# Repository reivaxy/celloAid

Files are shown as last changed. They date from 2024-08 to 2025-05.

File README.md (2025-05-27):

# celloAid

Check the license file.

No commercial use is authorized.

This is a set of aids to play the cello.

## Hand aid

shell_x folders contain shells built from a scan of the hand needing some aid

shell_3 has a bendable finger to press on the bow



## Bow aid

bow_x folders contain several iteration of a device to help hold the bow.

bow_3 and bow_4 have adjustable finger positions and a choice of various finger sizes.

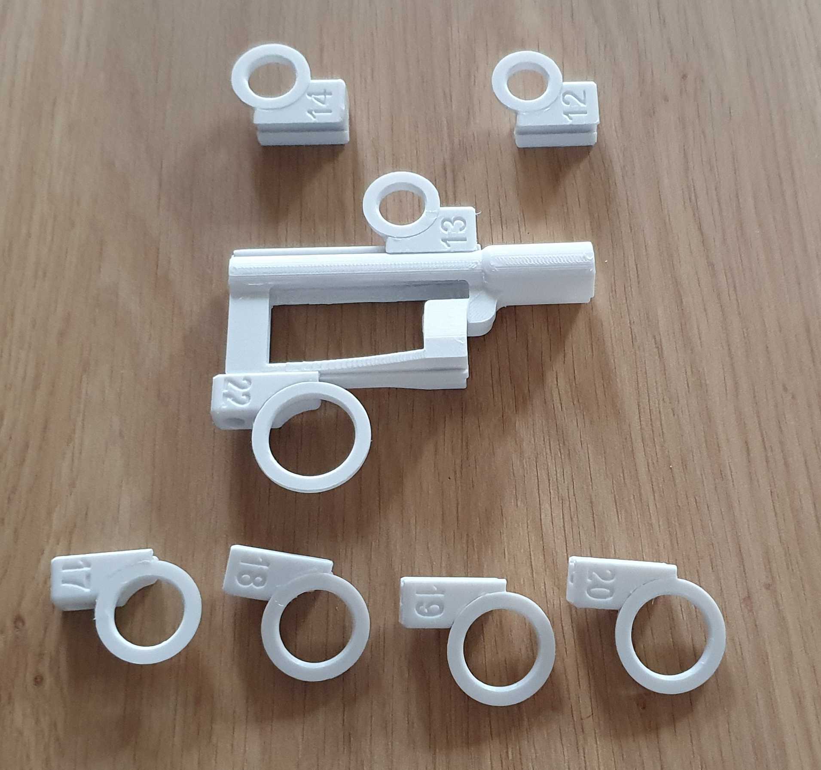
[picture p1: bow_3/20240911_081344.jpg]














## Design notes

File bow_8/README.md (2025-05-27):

This new prototype is an attempt at using the scan of the hand to offer accurate slots for the fingers.

The challenge of this approach is that nothing can be adjusted, we need to find the exact good position of the fingers relatively to each other and to the bow.

https://github.com/user-attachments/assets/44e5666f-47d5-4502-a32c-f4e456e8be6e



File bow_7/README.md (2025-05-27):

Unfortunately the silicon is too heavy, adding about 60g hence doubling the total weight of the device.

This new prototype is intended to be completed by thermo-plastic tightely adjusted around finger and thumb.

Therefore the finger and thumb slots were removed.

One challenge was to replace the low screw since it was on the removed thumb slot.

https://github.com/user-attachments/assets/684633d8-5a87-4853-8fdd-56d3ae45e7c3



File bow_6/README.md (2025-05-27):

bow_6 didn't provide enough grip, so I tried making the finger slots deeper. The top finger can now better push forward.

https://github.com/user-attachments/assets/e4d858df-fd63-4603-b8f2-d9ab5e832fca



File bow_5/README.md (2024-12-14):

New prototype without any hand shell, but only a device to put on the bow.

https://github.com/user-attachments/assets/7ac4e2ea-cd8e-4a7f-a282-7447c46ad186



Fingers will be set in silicon bi component mouldering putty to provide a firm grip.





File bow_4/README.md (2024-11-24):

The "nose" is longer and features a slidable pivot on which the hand aid bendable finger will be loosely attached to allow pressing down on the bow





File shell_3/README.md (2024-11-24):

Adding a bendable finger to press down on the bow



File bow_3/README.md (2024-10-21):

This iteration is intended to allow easy measurement for finger sizes and finger spacing.

Horizontal spacing is adjustable with rings sliding horizontally, with blocking screws, and sizing is made easy by changing the rings.

Small inconvenient is the sliders make the rings a bit farther from each other vertically, and some weight is added
(big slider + screw and nut), but it's just a prototype and once spacing and sizes are measured, next one will no longer be adjustable.

The hair tension can be adjusted at will without removing the device.



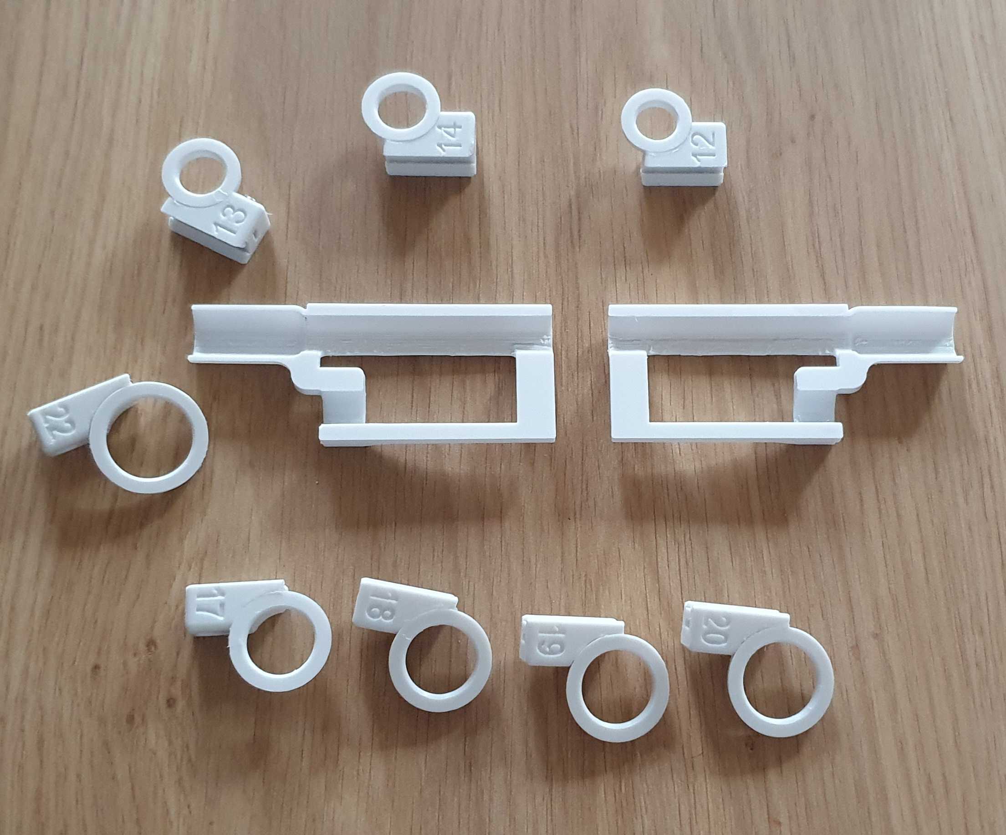
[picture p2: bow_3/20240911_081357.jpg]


To mitigate vertical spacing, I've worked on a new design for the thumb and finger rings, reducing distance by about 5mm.





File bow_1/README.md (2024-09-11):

One issue with this prototype is that it needs to be removed to adjust the hair tension.

The space between the two finger rings is too large for Soni

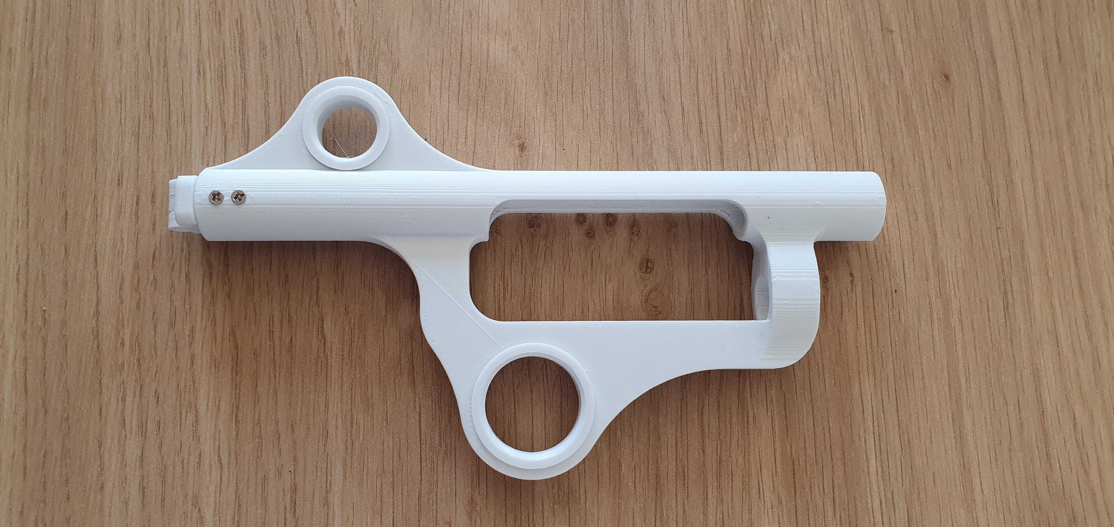
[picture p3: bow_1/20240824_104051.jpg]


A nice design is that the two halves are held together by the inner rings that also act as screws

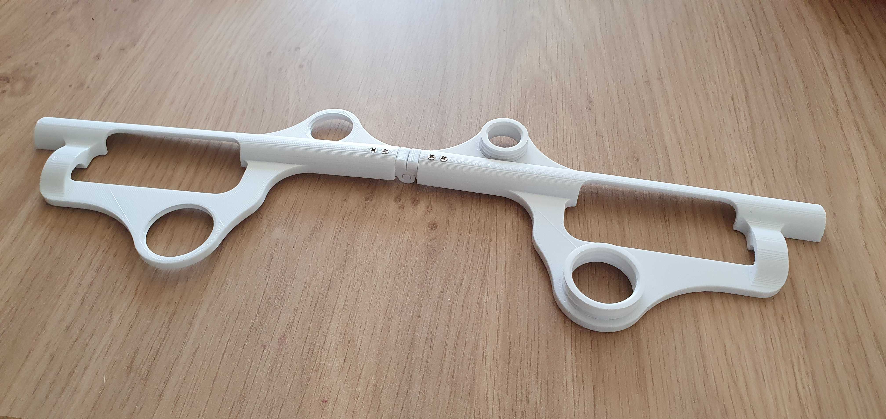
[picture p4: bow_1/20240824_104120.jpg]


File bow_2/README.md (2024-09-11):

Same issue than with bow_1 prototype, still needs to be removed to adjust the hair tension.

Compared to bow_1 prototype, the space between the two finger rings is better but not vertical enough to allow Soni use the full wrist flexion.

Also the finger rings are too large and don't provide a firm enough grip.

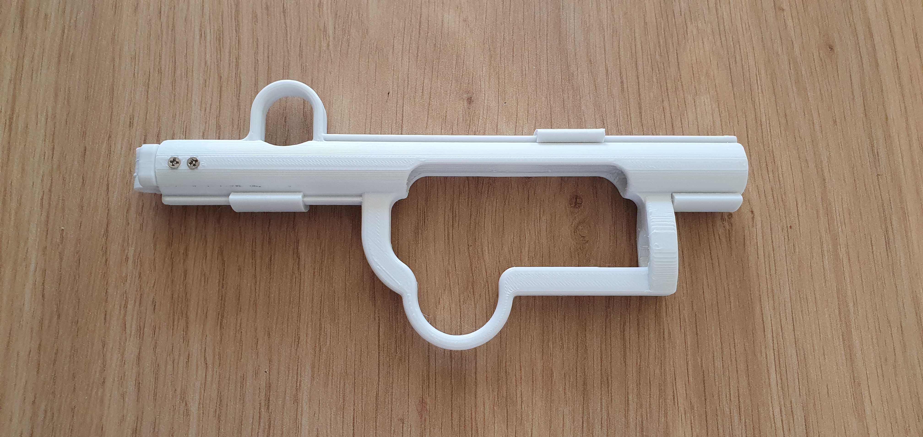
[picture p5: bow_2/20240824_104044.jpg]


The two halves are held together by sliding clips

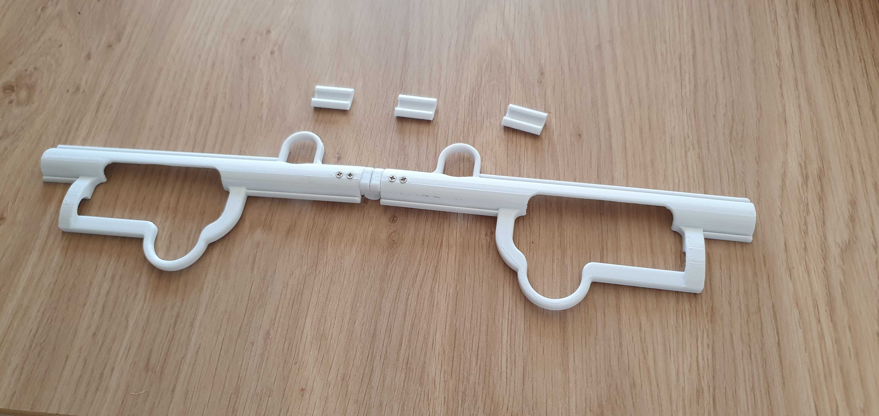
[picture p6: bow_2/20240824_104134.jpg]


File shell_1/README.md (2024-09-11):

This first shell was built from the scan from Soni's hand.

It was merely to validate designing a shell from a scan file.

It goes too low on the wrist which can no longer move enough, and too far on the fingers.

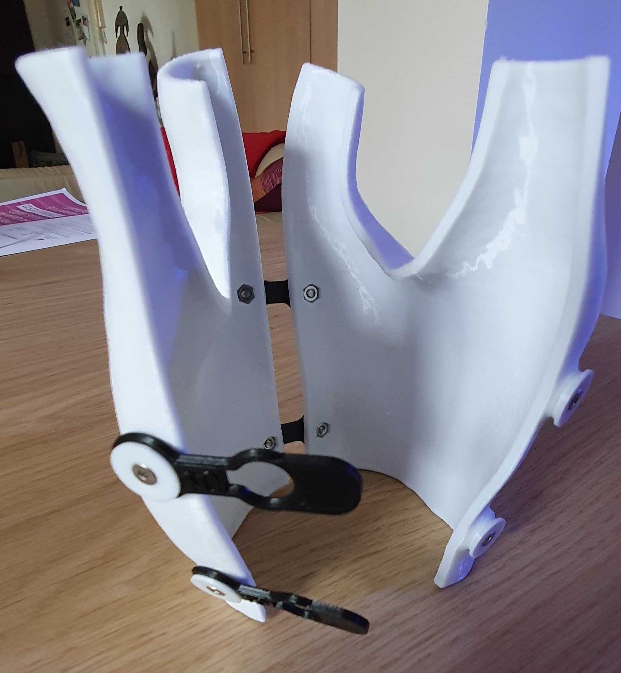
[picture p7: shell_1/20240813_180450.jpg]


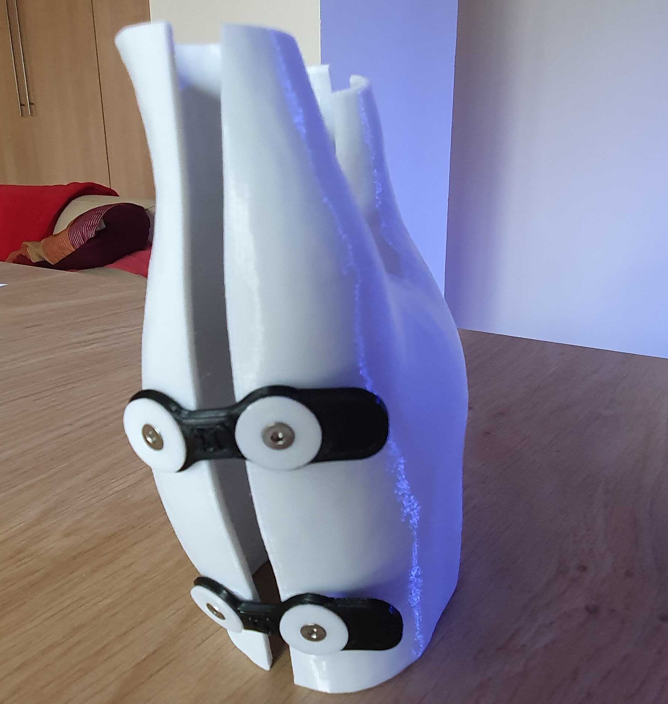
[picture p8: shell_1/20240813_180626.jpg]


Next iteration should have a third finger intended to apply some pressure on the bow.

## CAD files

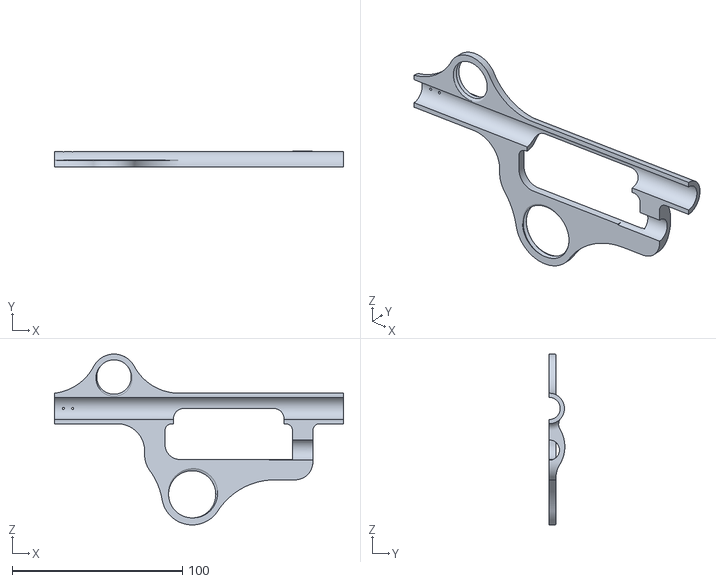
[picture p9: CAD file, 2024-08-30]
bow_1/tubeLeft.stl
170.0 x 9.24 x 100.5

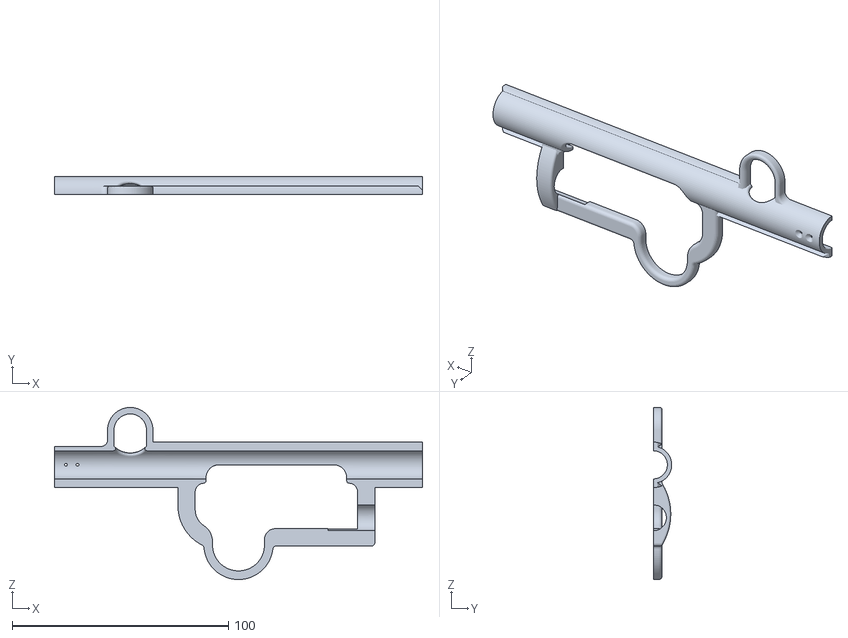
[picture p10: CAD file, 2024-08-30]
bow_2/tubeLeft.stl
170.0 x 8.50 x 79.5

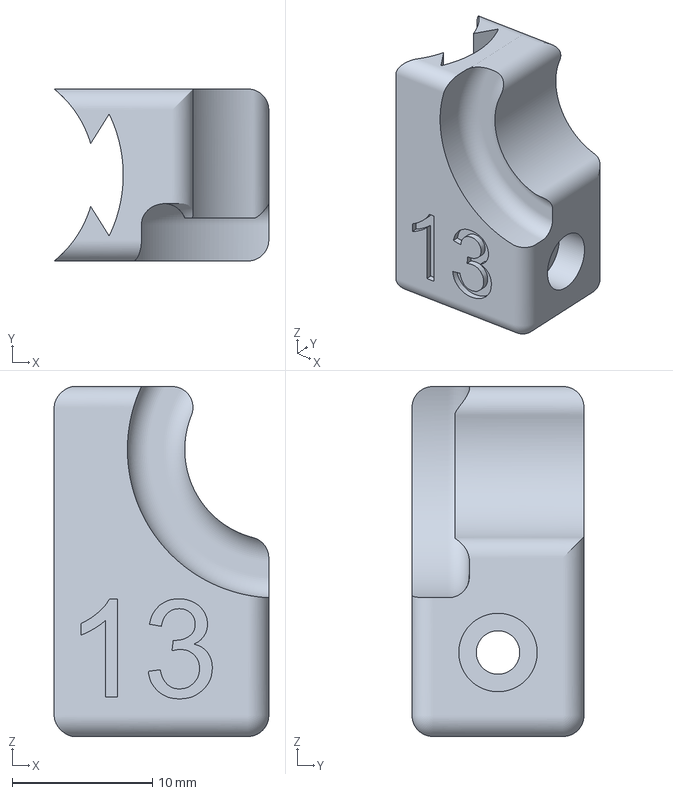
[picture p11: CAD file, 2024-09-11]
bow_3/finger/circles/fingerSlider13.3mf
15.3 x 12.3 x 25.0 mm

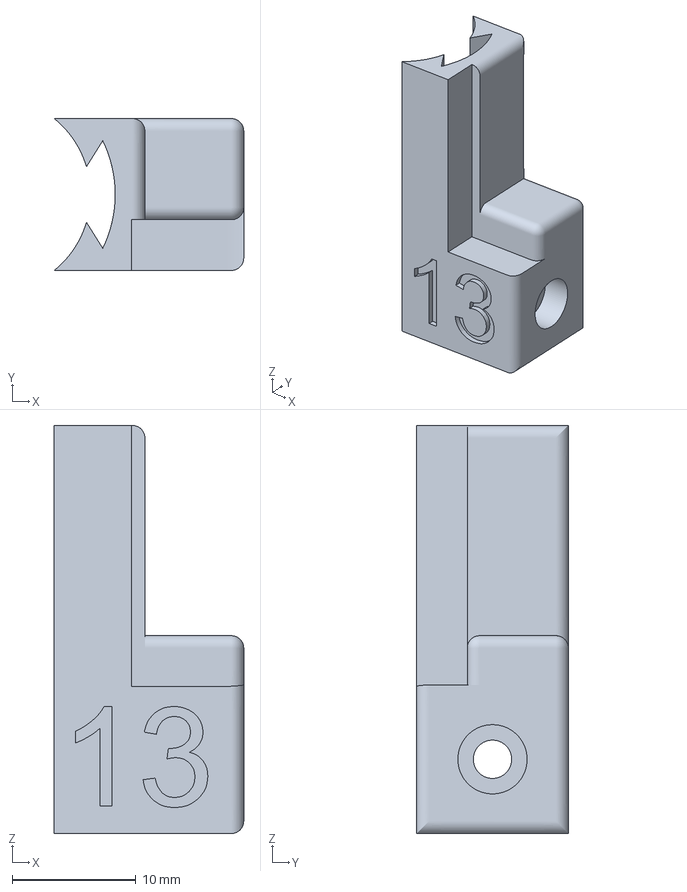
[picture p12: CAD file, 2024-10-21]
bow_3/finger/fingerSlider13.3mf
15.3 x 12.3 x 33.0 mm

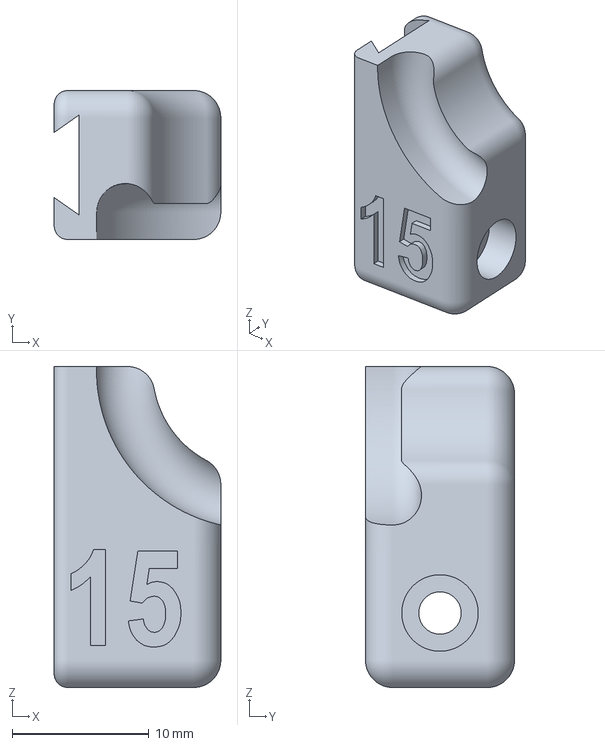
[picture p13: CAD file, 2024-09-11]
bow_3/thumb/circles/thumbSlider15.3mf
12.2 x 10.9 x 23.5 mm

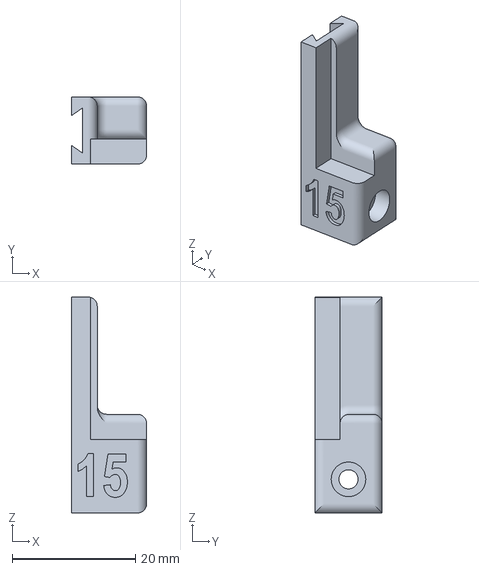
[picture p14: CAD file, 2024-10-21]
bow_3/thumb/thumbSlider15.3mf
12.2 x 10.9 x 35.0 mm

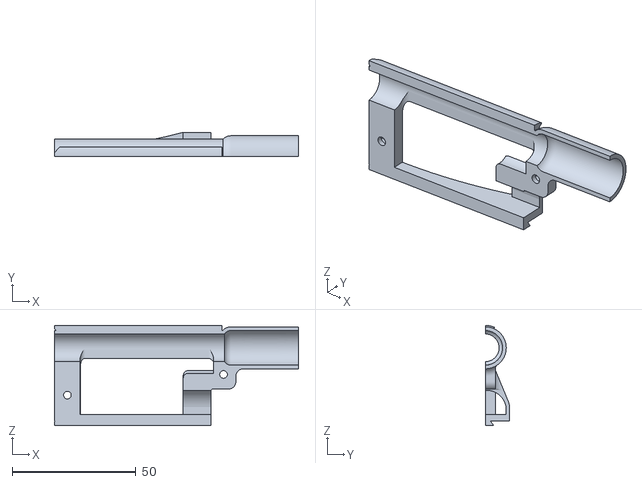
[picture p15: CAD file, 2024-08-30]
bow_3/tubeLeft.stl
98.7 x 9.90 x 40.6

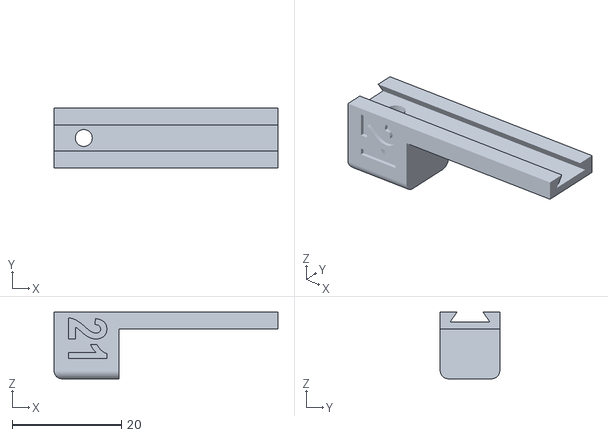
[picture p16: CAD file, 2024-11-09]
bow_4/thumbSlider21.stl
41.0 x 10.9 x 12.2

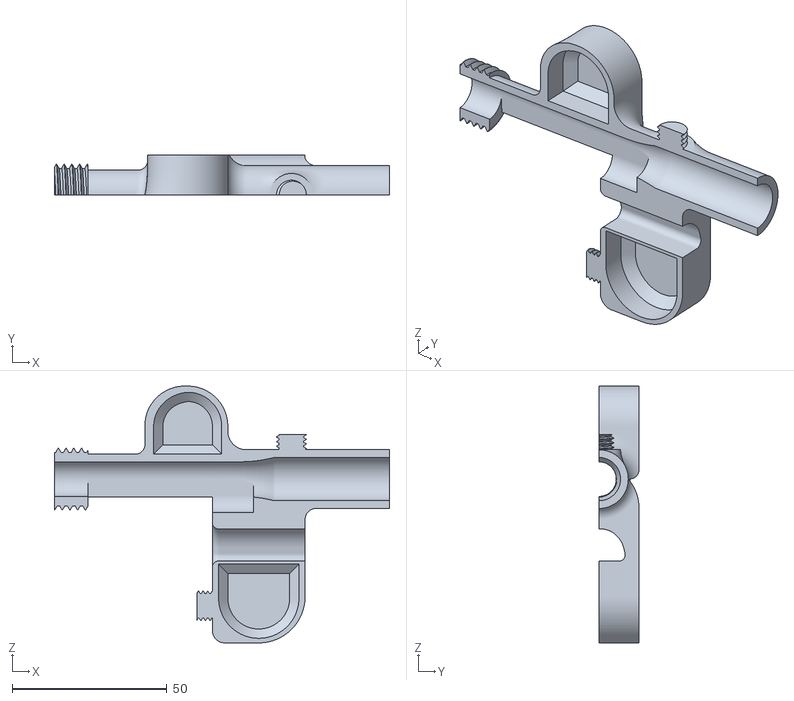
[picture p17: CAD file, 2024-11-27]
bow_5/bowBackHollow.stl
108.4 x 13.0 x 83.1

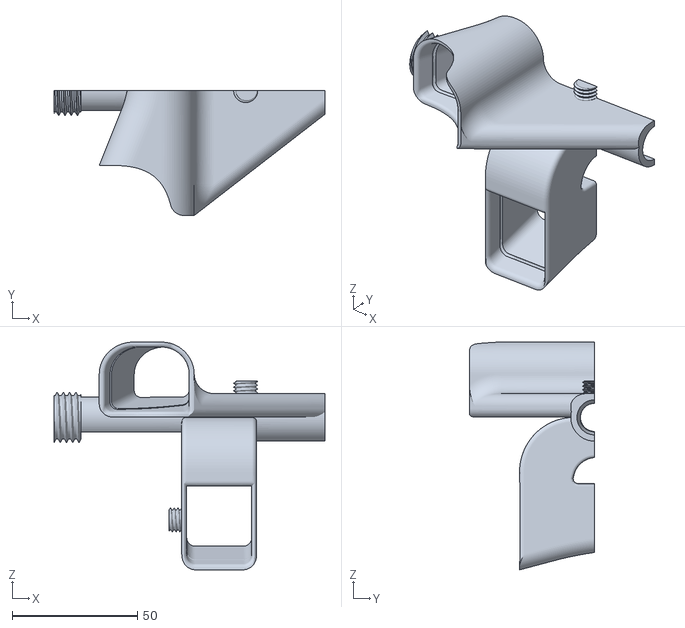
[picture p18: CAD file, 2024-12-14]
bow_6/front.stl
108.4 x 50.0 x 91.1

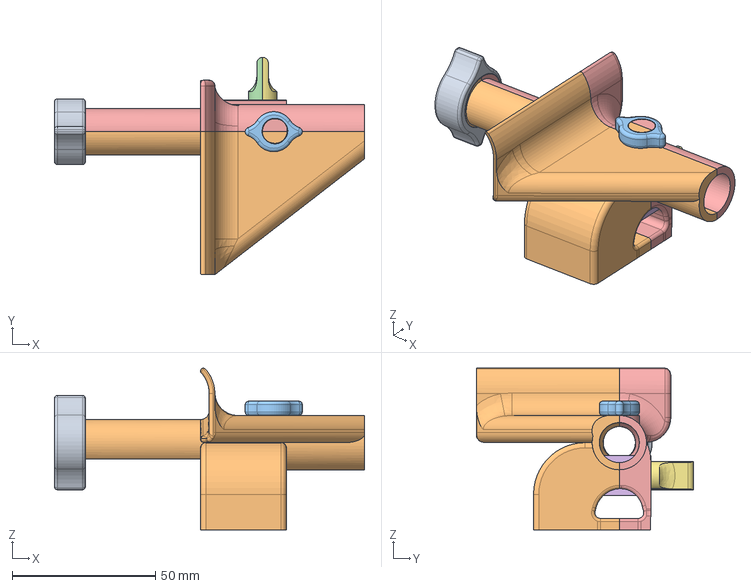
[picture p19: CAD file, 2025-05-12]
bow_7/step/bow_7.step
108.4 x 76.0 x 56.5 mm

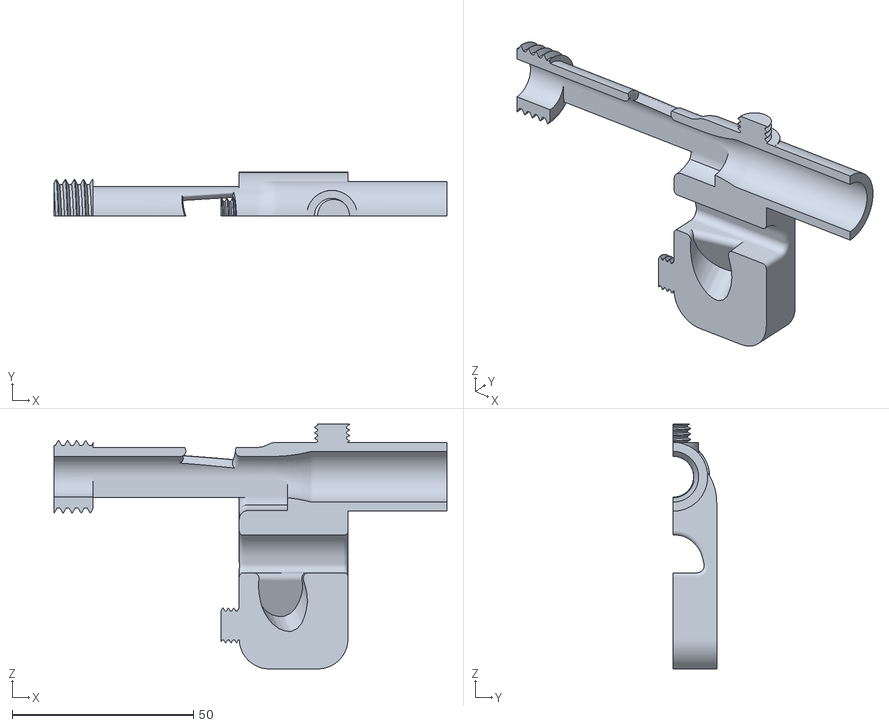
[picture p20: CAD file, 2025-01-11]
bow_8/back.stl
108.4 x 12.0 x 67.5

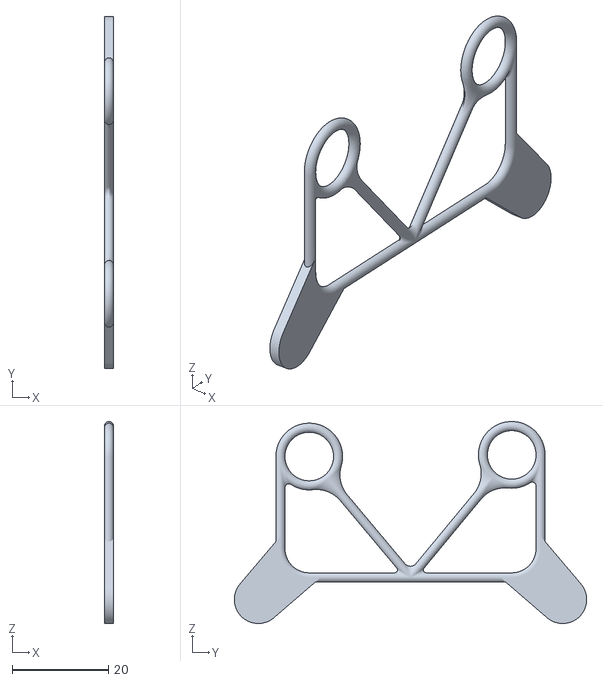
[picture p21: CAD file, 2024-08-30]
shell_1/tpuDualHook.stl
1.90 x 73.4 x 42.1

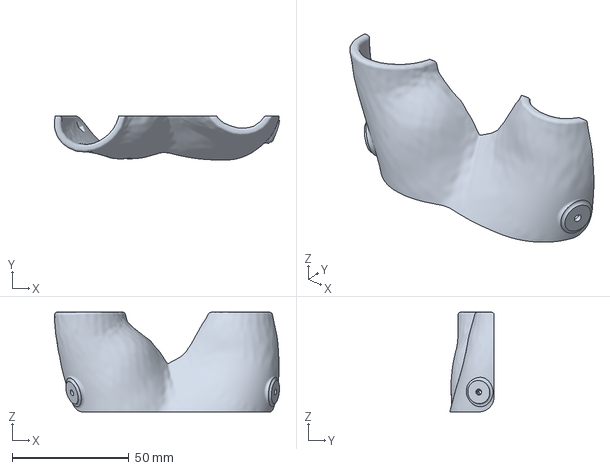
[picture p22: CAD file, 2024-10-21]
shell_2/bottom.3mf
96.5 x 19.0 x 42.8 mm

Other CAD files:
shell_3/index.stl
bow_1/hinge v2.stl
bow_2/lock.stl
bow_3/finger/circles/fingerRing.3mf
bow_1/bigScrew.stl
bow_1/smallScrew.stl
bow_1/testBigtubeRight.stl
bow_1/testtubeRight.stl
bow_1/tubeRight.stl
bow_2/hinge v2.stl
bow_2/tubeRight.stl
bow_3/finger/circles/fingerRing12.stl
bow_3/finger/circles/fingerRing13.stl
bow_3/finger/circles/fingerRing14.stl
bow_3/finger/circles/fingerRing15.stl
bow_3/finger/circles/fingerSlider12.3mf
bow_3/finger/circles/fingerSlider12.stl
bow_3/finger/circles/fingerSlider13.stl
bow_3/finger/circles/fingerSlider14.3mf
bow_3/finger/circles/fingerSlider14.stl
bow_3/finger/circles/fingerSlider15.3mf
bow_3/finger/circles/fingerSlider15.stl
bow_3/finger/fingerRing12.stl
bow_3/finger/fingerRing13.stl
bow_3/finger/fingerRing14.stl
bow_3/finger/fingerRing15.stl
bow_3/finger/fingerRing16.stl
bow_3/finger/fingerRings.3mf
bow_3/finger/fingerSlider12.3mf
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

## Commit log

2024-08-30 first STLs
    [bigScrew.stl, fingerRing12.stl, fingerRing13.stl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]
2024-09-11 sub folders
    [fingerRing.3mf, fingerRing12.stl, fingerRing13.stl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]
2024-10-21 New ring designs to minimize vertical space between thumb and finger.
    [bottom.3mf, fingerRing.3mf, fingerRing12.stl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]
2024-11-09 Iteration with bendable additional finger to press down on the bow
    [fingerRing18.stl, fingerSlider18.stl, index.stl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]
2024-11-24 Fifth prototype bow_5
    [bottomScrew.stl, bowBack.stl, bowFront.stl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]
2024-11-27 Added hollow back options
    [bowBackHollow.stl, bowBackHollower.stl]
2024-12-14 6th prototype
2024-12-14 adding stls
    [bottom.stl, bottomScrew.stl, front.stl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]
2025-01-11 7th prototype
    [back.stl, backScrew (1).stl, backScrew.stl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]
2025-01-11 adding top and bottom screws (same as previous proto)
    [bottomScrew.stl, topScrew.stl]
2025-01-11 Using the scan of the hand
    [back.stl, bottomScrew.stl, lowScrew.stl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]
2025-05-12 Adding step file
    [bow_7.step]
